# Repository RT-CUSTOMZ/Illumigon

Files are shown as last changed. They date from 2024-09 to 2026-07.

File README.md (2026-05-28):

# 💡 Illumigon

Die modularen smarten Leuchtpanels mit Wifi-Konnektivität, die Ihr auf der Campuswoche bauen könnt.

---

## 📦 Features

- [x] Individuell adressierbare LEDs (WS2811)
- [x] WLAN-fähige Steuerung via ESP32
- [x] Konfigurierbare Animationen und Farbpaletten
- [x] Open Source Hardware + Software (WLED)
- [x] Home Assistant Integration
- [x] Modular steckbar
- [x] Keine Kabelsalat

---

## 📁 Dateiübersicht

| Pfad / Datei | Beschreibung |
|---|---|
| `Fusion 360/` | Fusion 360 Archiv und STEP-Modell |
| `Gerber/` | Leiterplattenlayouts im Gerber Format |
| `KiCad/` | Leiterplattenlayouts im KiCad 9 Format  |
| `STLs/` | 3D-Modell im STL-Format für den 3D-Druck|
| `SVGs/` | Vectorgrafiken zum Laserschneiden und Gravieren |

## 🧾 Stückliste / Teilebestellung

### 🧠 ESP32 WLED Controller

| Bauteil | Referenz | Wert | Footprint | Menge | Link  |
|---|---|---|---|---|---|
| Keramikkondensator | C3, C4, C5, C7, C8, C9, C10 | 100n | SMD 1206 | 7 | |
| Keramikkondensator | C11, C12 | 22u | SMD 1206 | 2 | |
| Elektrolytkondensator | C1 | 470u | C_Elec_10x10.2 | 1 | |
| Keramikkondensator | C2 | 1u0 | SMD 1206 | 1 | |
| Keramikkondensator | C6 | 10u | SMD 1206 | 1 | |
| Dichschichtwiderstand | R3, R6, R9 | 100R | SMD 0805 | 3 | |
| Dichschichtwiderstand | R8, R11, R12 | 10K | SMD 1206 | 3 | |
| Dichschichtwiderstand | R4, R5 | 5K1 | SMD 1206 | 2 | |
| Dichschichtwiderstand | R7, R10 | 4K7 | SMD 0805 | 2 | |
| Dichschichtwiderstand | R1 | 2K0 | SMD 0805 | 1 | |
| Dichschichtwiderstand | R2 | 470R | SMD 0805 | 1 | |
| Leistungsinduktor | L1 | 4u7 | 7.3x6.6mm | 1 | |
| Leuchtdiode | D1, D2, D3, D5, D6 | LED | SMD 0805 | 5 | |
| Schottky-Diode | D4, D7 | SS34 | SMA | 2 | |
| 3.3V Spannungswandler | U1 | AMS1117-3.3 | SOT-223-3 | 1 | |
| 32-bit Mikrocontroller  | U2 | ESP32-WROOM-32E | | 1 | |
| 5V Synchr.-Schaltregler | U3 | AP63205WU | TSOT-23-6 | 1 | |
| 420Mbps Levelshifter | U4 | SN74LVC1T45DBV | SOT-23-6 | 1 | |
| USB-UART Transceiver | U5 | CH340C | SOIC-16 | 1 | |
| Bipolartransistor | Q2, Q3 | BC857 | SOT-23 | 2 | |
| Bipolartransistor | Q4, Q5 | MMBT3904 | SOT-23 | 2 | |
| P-Kanal MOSFET | Q1 | Q_PMOS_GDS | TO-252-2 | 1 | |
| USB-C-Buchse 16-Pin | J1 | USB_C_Receptacle_USB2.0_16P | GCT USB4105 | 1 | |
| Hohlsteckerbuchse | J2 | Barrel_Jack_Switch | | 1 | |
| Pinheader 2.54 2x3 | J3 | Conn_02x03_Odd_Even | 2x03 P2.54mm Vertical | 1 | |

### 💡 Komponenten je Panel

| Bauteil | Referenz | Wert | Footprint | Menge | Link |
|---|---|---|---|---|---|
| Platine | Ecke | | | 3 | [GitHub](https://github.com/RT-CUSTOMZ/Illumigon/blob/V4/Gerber/Ecke.zip) |
| Platine | Seite | | | 3 | [GitHub](https://github.com/RT-CUSTOMZ/Illumigon/blob/V4/Gerber/Seite.zip) |
| Plexiglas | Lichtleiter | 4mm klar | Acrylglas GS | 1 | [GitHub](https://github.com/RT-CUSTOMZ/Illumigon/blob/e6f71768b751d2ca16ff6e7ad1a84dd5374f7dc3/SVGs/Light_Guide_Panel_fein.svg) |
| Plexiglas | Diffusor | 3mm opal | Acrylglas XT opal 70105  | 1 | [GitHub](https://github.com/RT-CUSTOMZ/Illumigon/blob/e6f71768b751d2ca16ff6e7ad1a84dd5374f7dc3/SVGs/Diffusor.svg) |
| Pinheader 2x3  | J1 | 02x03 | Vertikal | 3 | [LCSC](https://www.lcsc.com/product-detail/C492420.html) |
| Pinheader 1x5  | J2, J3 | 01x05 | Horizontal | 6 | [LCSC](https://www.lcsc.com/product-detail/C492413.html) |
| Platine | Verbinder | | | 1 | [GitHub](https://github.com/RT-CUSTOMZ/Illumigon/blob/V4/Gerber/Verbinder.zip) |
| Pinsocket 2x3  | J1, J2 | 02x03 | Vertikal | 2 | [LCSC](https://www.lcsc.com/product-detail/C5116527.html) |
| Pinheader 1x2  | J3, J4 | 01x02 | Vertikal | 2 | [LCSC](https://www.lcsc.com/product-detail/C492401.html) |
| Jumper 1x2 | | 01x02 | | 1 | [LCSC](https://www.lcsc.com/product-detail/C100114.html) |
| Schraube | | PZ 3x10 | | 3 | [Schraubenhimmel](https://www.schraubenhimmel.de/schrauben/senkkopf/spanplattenschrauben-kreuzschlitz/65940/spax-wirox-senkkopf-kreuzschlitz-pz-1-3x10-mm-vollgewinde) |
| 3D-Druck | | Deckel u.  | | 3 | [GitHub](https://github.com/RT-CUSTOMZ/Illumigon/blob/V4/STLs/Deckel_unten%20v49.stl) |
| 3D-Druck | | Deckel m.  | | 3 | [GitHub](https://github.com/RT-CUSTOMZ/Illumigon/blob/V4/STLs/Deckel_mitte%20v45.stl) |
| 3D-Druck | | Verbinder  | | 2 | [GitHub](https://github.com/RT-CUSTOMZ/Illumigon/blob/V4/STLs/Verbinder%20v9.stl) |

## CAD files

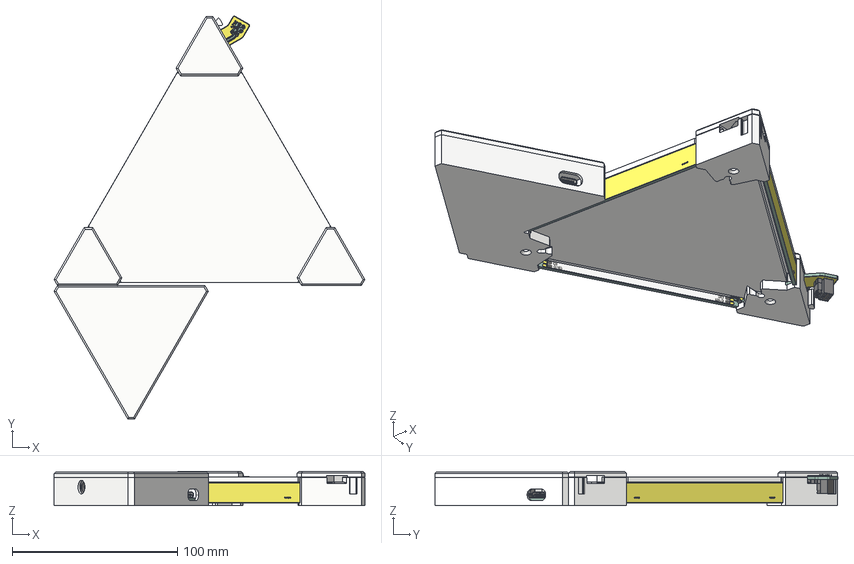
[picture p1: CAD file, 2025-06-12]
Fusion 360/Zusammenbau v36.step
187.9 x 243.6 x 20.8 mm
PinHeader_1x05_P254mm_Horizontal x 6
PinHeader_2x03_P254mm_Vertical x 3
Ecke_track_1 x 3
Ecke_track_2 x 3
Ecke_track_3 x 3
Ecke_track_4 x 3
Ecke_track_5 x 3
Ecke_track_6 x 3
Ecke_track_7 x 3
Ecke_track_8 x 3
Ecke_track_10 x 3
Ecke_track_11 x 3
Ecke_track_12 x 3
Ecke_track_13 x 3
Ecke_track_14 x 3
Ecke_track_15 x 3
Ecke_track_16 x 3
Ecke_track_17 x 3
Ecke_track_18 x 3
Ecke_track_19 x 3
Ecke_track_20 x 3
Ecke_track_21 x 3
Ecke_track_22 x 3
Ecke_track_23 x 3
Ecke_track_24 x 3
Ecke_track_25 x 3
Ecke_zone_1 x 3
Ecke_zone_2 x 3
Ecke_zone_3 x 3
Ecke_zone_4 x 3
Ecke_zone_5 x 3
Ecke_zone_6 x 3
Ecke_zone_7 x 3
Ecke_zone_8 x 3
Ecke_zone_9 x 3
Ecke_zone_10 x 3
Ecke_zone_11 x 3
Ecke_zone_12 x 3
Ecke_zone_13 x 3
Ecke_zone_14 x 3
Ecke_zone_15 x 3
Ecke_zone_16 x 3
Ecke_zone_17 x 3
Ecke_pad_1 x 3
Ecke_pad_2 x 3
Ecke_pad_3 x 3
Ecke_pad_4 x 3
Ecke_pad_5 x 3
Ecke_pad_6 x 3
Ecke_pad_7 x 3
Ecke_pad_8 x 3
Ecke_pad_9 x 3
Ecke_pad_10 x 3
Ecke_pad_11 x 3
Ecke_pad_12 x 3
Ecke_pad_13 x 3
Ecke_pad_14 x 3
Ecke_pad_15 x 3
Ecke_pad_18 x 3
Ecke_pad_19 x 3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

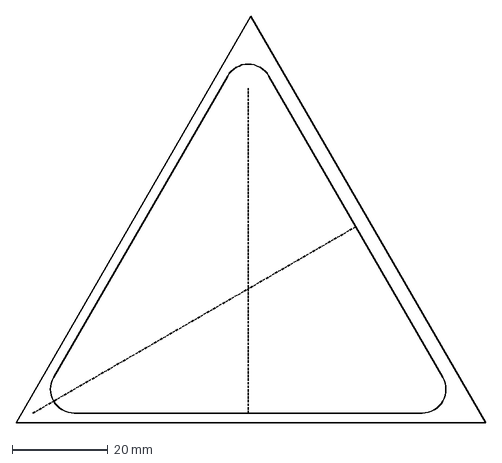
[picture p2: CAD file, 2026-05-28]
KiCad/Controller_v4.3/Dreieck_90mm.dxf
98.1 x 84.9 mm

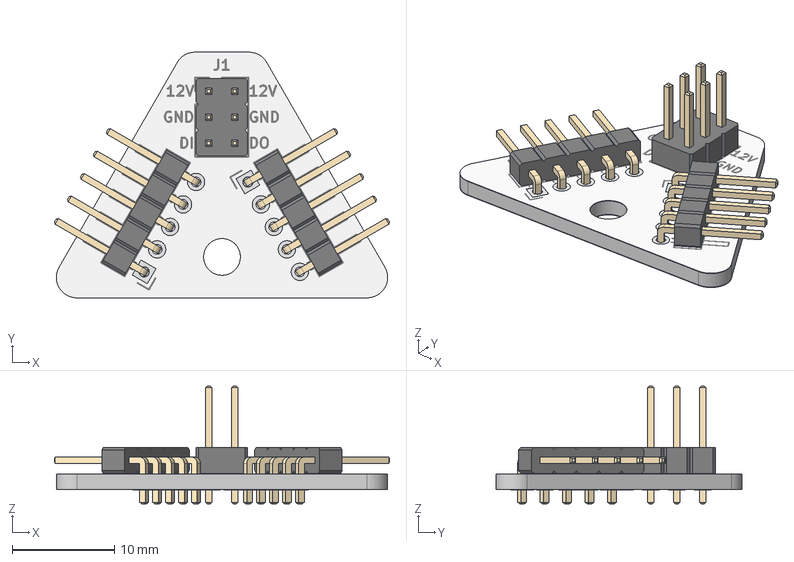
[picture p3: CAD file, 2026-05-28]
KiCad/Ecke/Ecke.step
32.8 x 24.0 x 11.5 mm
PinHeader_1x05_P2.54mm_Horizontal x 2
PinHeader_2x03_P2.54mm_Vertical
Ecke_pad
Ecke_silkscreen
Ecke_soldermask
Ecke_PCB

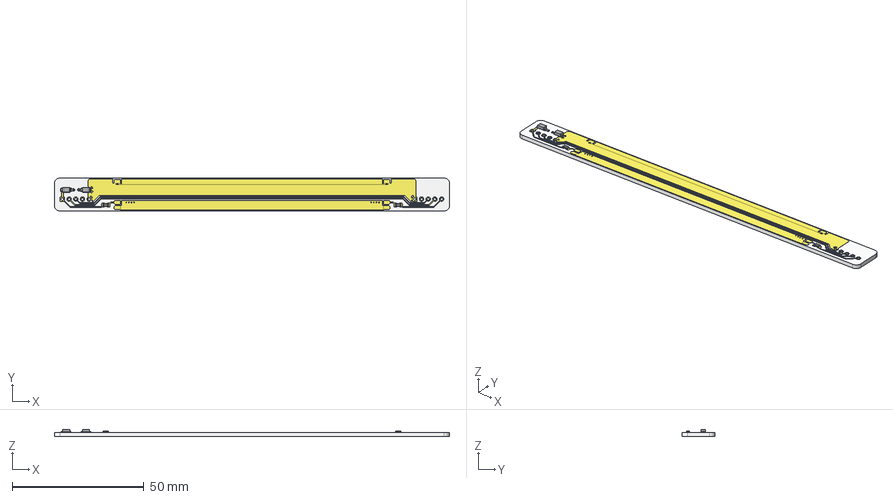
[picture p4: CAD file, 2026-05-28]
KiCad/Seite_v4.3/Seite_v4.3.step
150.0 x 12.5 x 2.63 mm
D_SMF x 2
R_0805_2012Metric x 2
Seite_v4.3_copper
Seite_v4.3_PCB

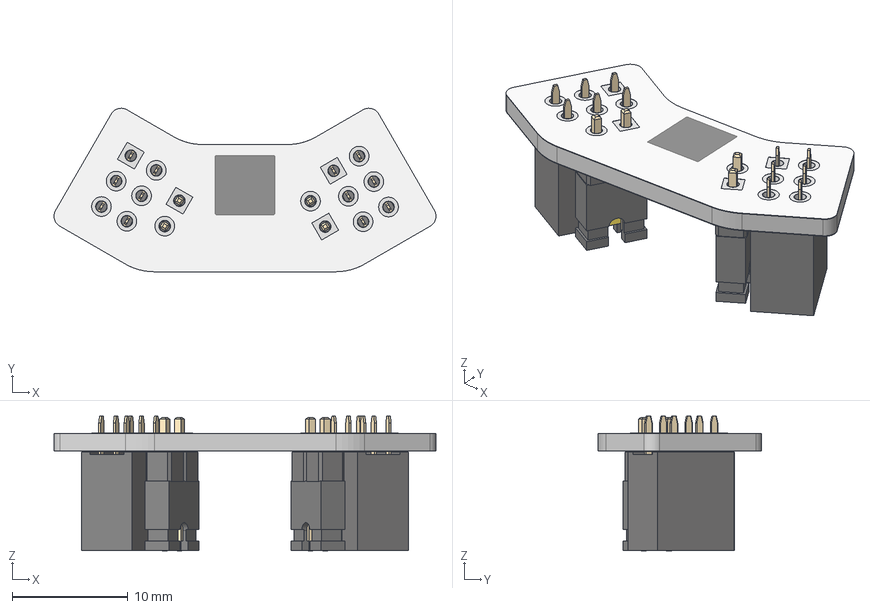
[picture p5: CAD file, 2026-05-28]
KiCad/Verbinder/Verbinder_Jumper.step
33.0 x 14.1 x 11.6 mm
PinSocket_2x03_P2.54mm_Vertical x 2
PinHeader_1x02_P2.54mm_Vertical x 2
Jumper x 2
Verbinder_pad
Verbinder_silkscreen
Verbinder_soldermask
Verbinder_PCB

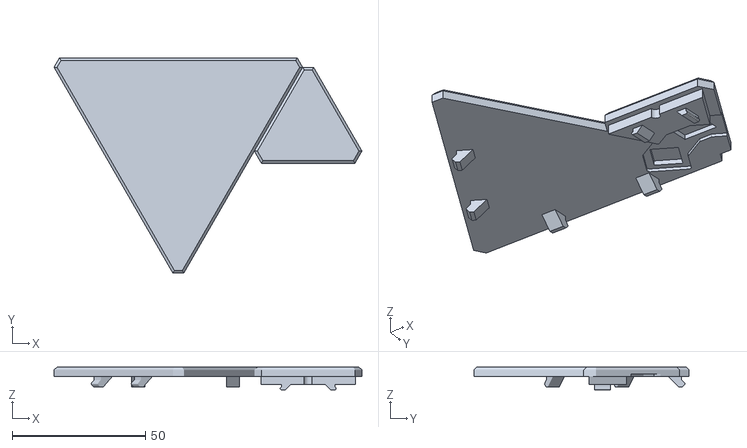
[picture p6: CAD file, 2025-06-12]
STLs/SMD_Controller_Gehäuse_Oberseite_v10.stl
115.4 x 80.7 x 8.50

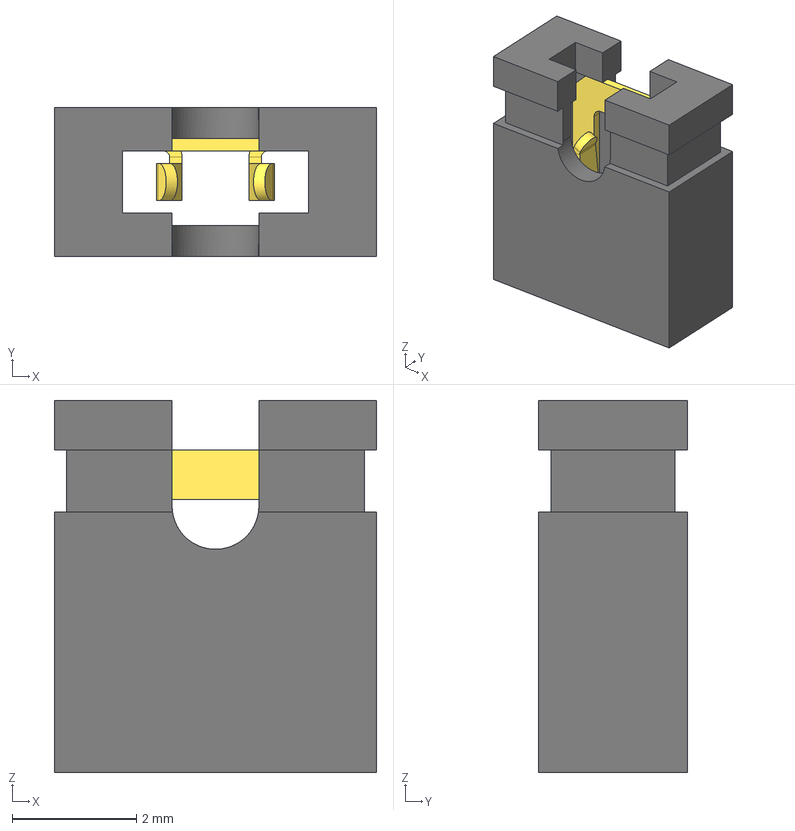
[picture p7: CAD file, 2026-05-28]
KiCad/Verbinder/Jumper.step
5.20 x 2.40 x 6.00 mm

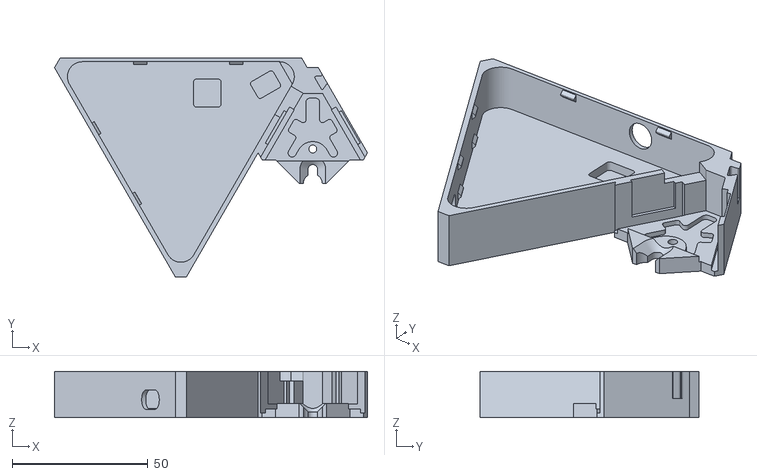
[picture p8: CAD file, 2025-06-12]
STLs/SMD_Controller_Gehäuse_Unterseite_v10.stl
115.4 x 80.7 x 17.0

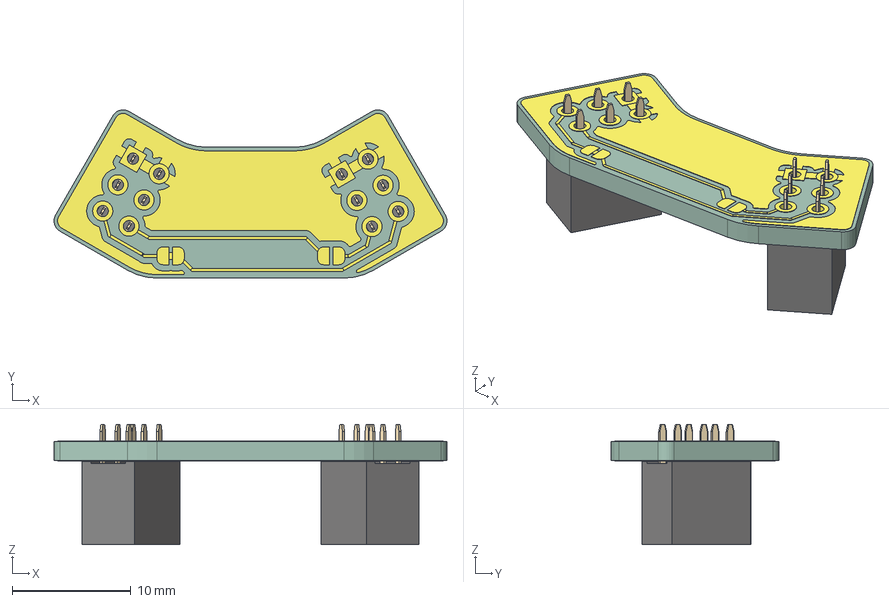
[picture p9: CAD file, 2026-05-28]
KiCad/Verbinder/Verbinder.step
33.0 x 14.1 x 10.1 mm
PinSocket_2x03_P254mm_Vertical x 2
_autosave-Verbinder_track_1
_autosave-Verbinder_track_2
_autosave-Verbinder_track_3
_autosave-Verbinder_track_4
_autosave-Verbinder_track_5
_autosave-Verbinder_track_6
_autosave-Verbinder_track_7
_autosave-Verbinder_track_8
_autosave-Verbinder_track_9
_autosave-Verbinder_track_10
_autosave-Verbinder_track_11
_autosave-Verbinder_track_12
_autosave-Verbinder_track_13
_autosave-Verbinder_track_14
_autosave-Verbinder_track_15
_autosave-Verbinder_track_16
_autosave-Verbinder_zone_1
_autosave-Verbinder_zone_2
_autosave-Verbinder_zone_3
_autosave-Verbinder_zone_4
_autosave-Verbinder_pad_1
_autosave-Verbinder_pad_2
_autosave-Verbinder_pad_3
_autosave-Verbinder_pad_4
_autosave-Verbinder_pad_5
_autosave-Verbinder_pad_6
_autosave-Verbinder_pad_7
_autosave-Verbinder_pad_8
_autosave-Verbinder_pad_9
_autosave-Verbinder_pad_10
_autosave-Verbinder_pad_11
_autosave-Verbinder_pad_12
_autosave-Verbinder_pad_13
_autosave-Verbinder_pad_14
_autosave-Verbinder_pad_15
_autosave-Verbinder_pad_16
_autosave-Verbinder_pad_17
_autosave-Verbinder_pad_18
_autosave-Verbinder_pad_19
_autosave-Verbinder_pad_20
_autosave-Verbinder_pad_21
_autosave-Verbinder_pad_22
_autosave-Verbinder_pad_23
_autosave-Verbinder_pad_24
_autosave-Verbinder_pad_25
_autosave-Verbinder_pad_26
_autosave-Verbinder_pad_27
_autosave-Verbinder_pad_28
_autosave-Verbinder_pad_29
_autosave-Verbinder_pad_30
_autosave-Verbinder_pad_31
_autosave-Verbinder_pad_32
_autosave-Verbinder_pad_33
_autosave-Verbinder_pad_34
_autosave-Verbinder_pad_35
_autosave-Verbinder_pad_36
_autosave-Verbinder_pad_37
_autosave-Verbinder_pad_38
_autosave-Verbinder_pad_39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

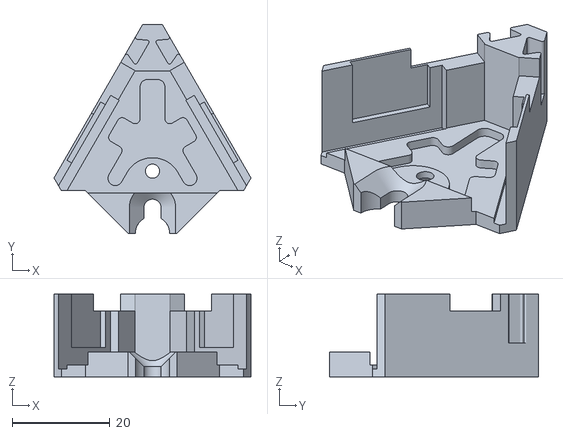
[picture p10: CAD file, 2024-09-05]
STLs/Deckel_unten v49.stl
40.4 x 42.8 x 17.0

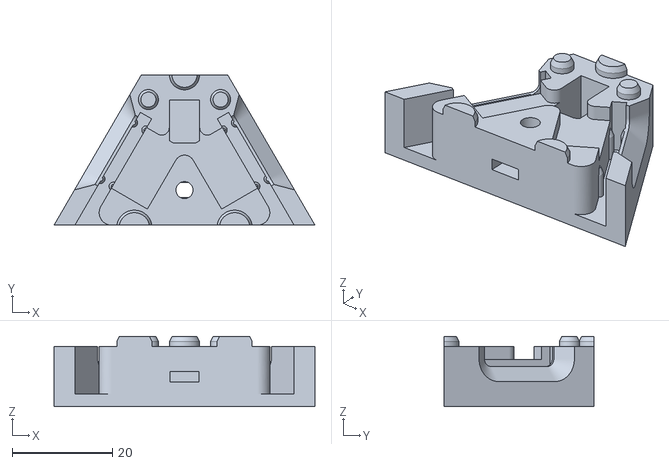
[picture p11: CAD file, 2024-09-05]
STLs/Löthilfe v13.stl
52.1 x 30.0 x 14.0

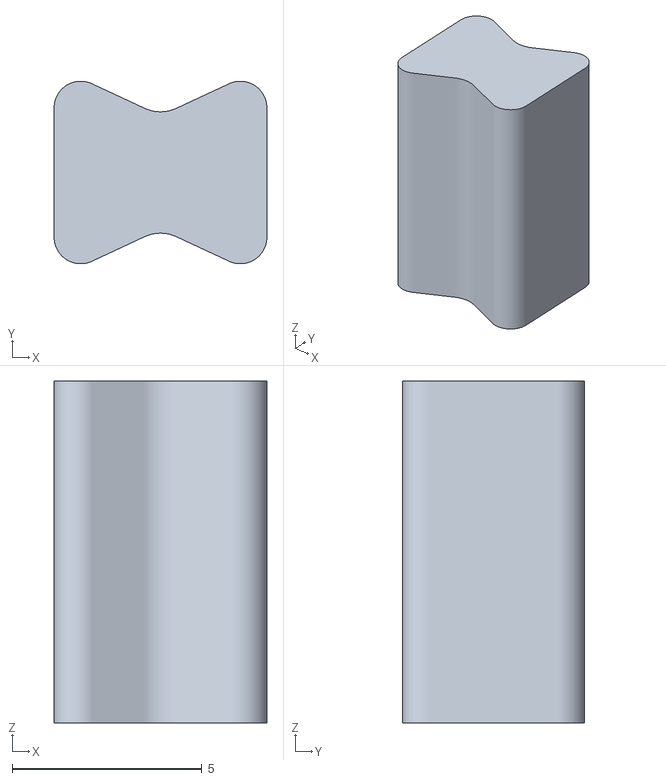
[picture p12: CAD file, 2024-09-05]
STLs/Verbinder v9.stl
5.60 x 4.80 x 9.00

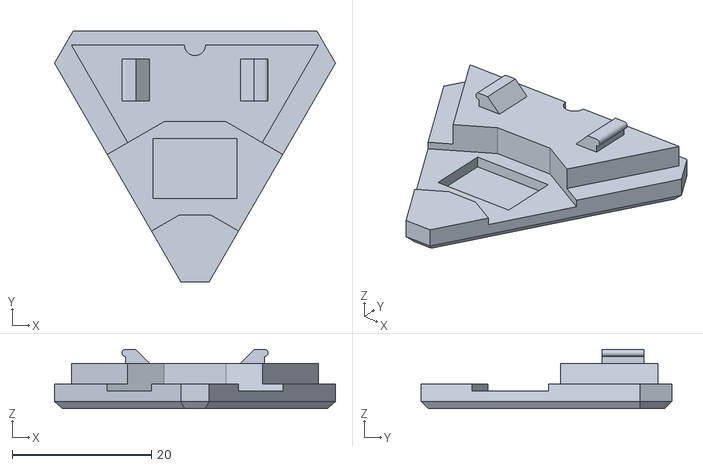
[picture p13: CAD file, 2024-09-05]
STLs/Deckel_oben v48.stl
40.4 x 36.0 x 8.50

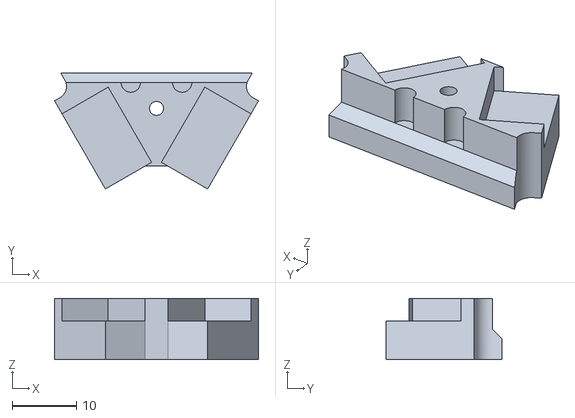
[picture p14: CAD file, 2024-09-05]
STLs/Deckel_mitte v45.stl
31.7 x 18.0 x 9.50

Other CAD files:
Fusion 360/Löthilfe v13.f3z
Fusion 360/Zusammenbau v36.f3z

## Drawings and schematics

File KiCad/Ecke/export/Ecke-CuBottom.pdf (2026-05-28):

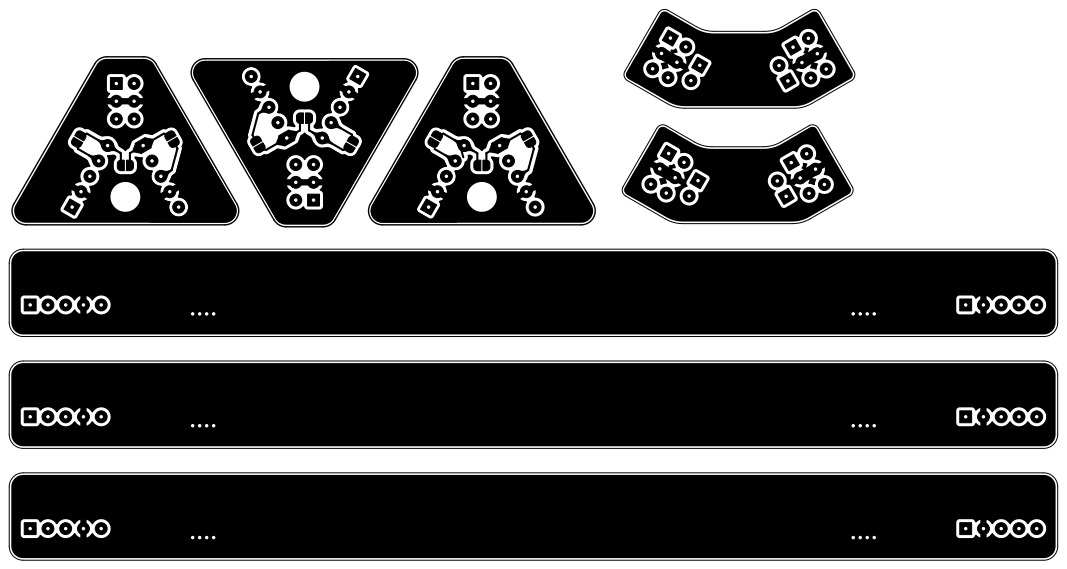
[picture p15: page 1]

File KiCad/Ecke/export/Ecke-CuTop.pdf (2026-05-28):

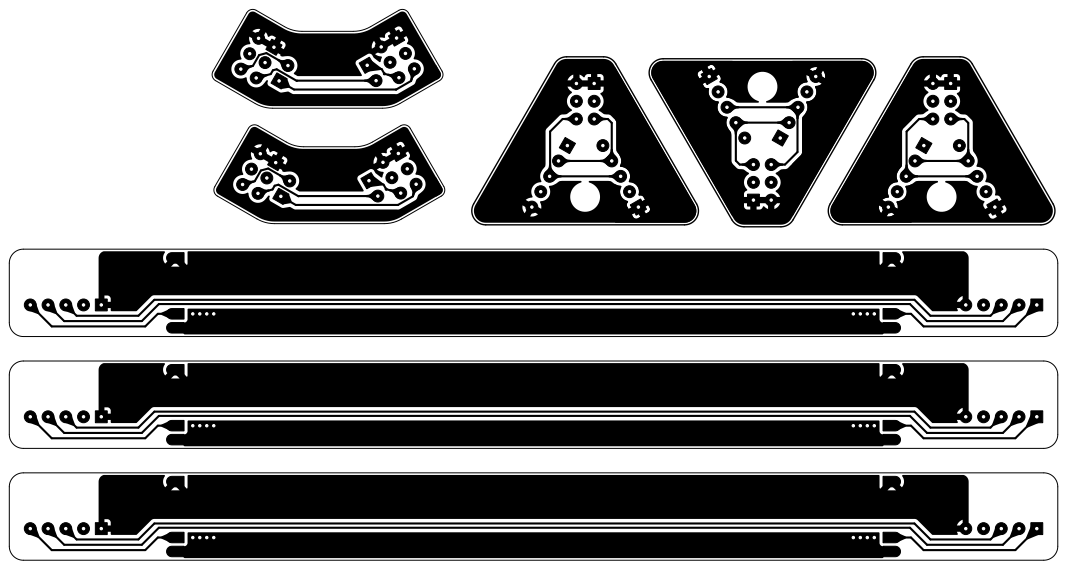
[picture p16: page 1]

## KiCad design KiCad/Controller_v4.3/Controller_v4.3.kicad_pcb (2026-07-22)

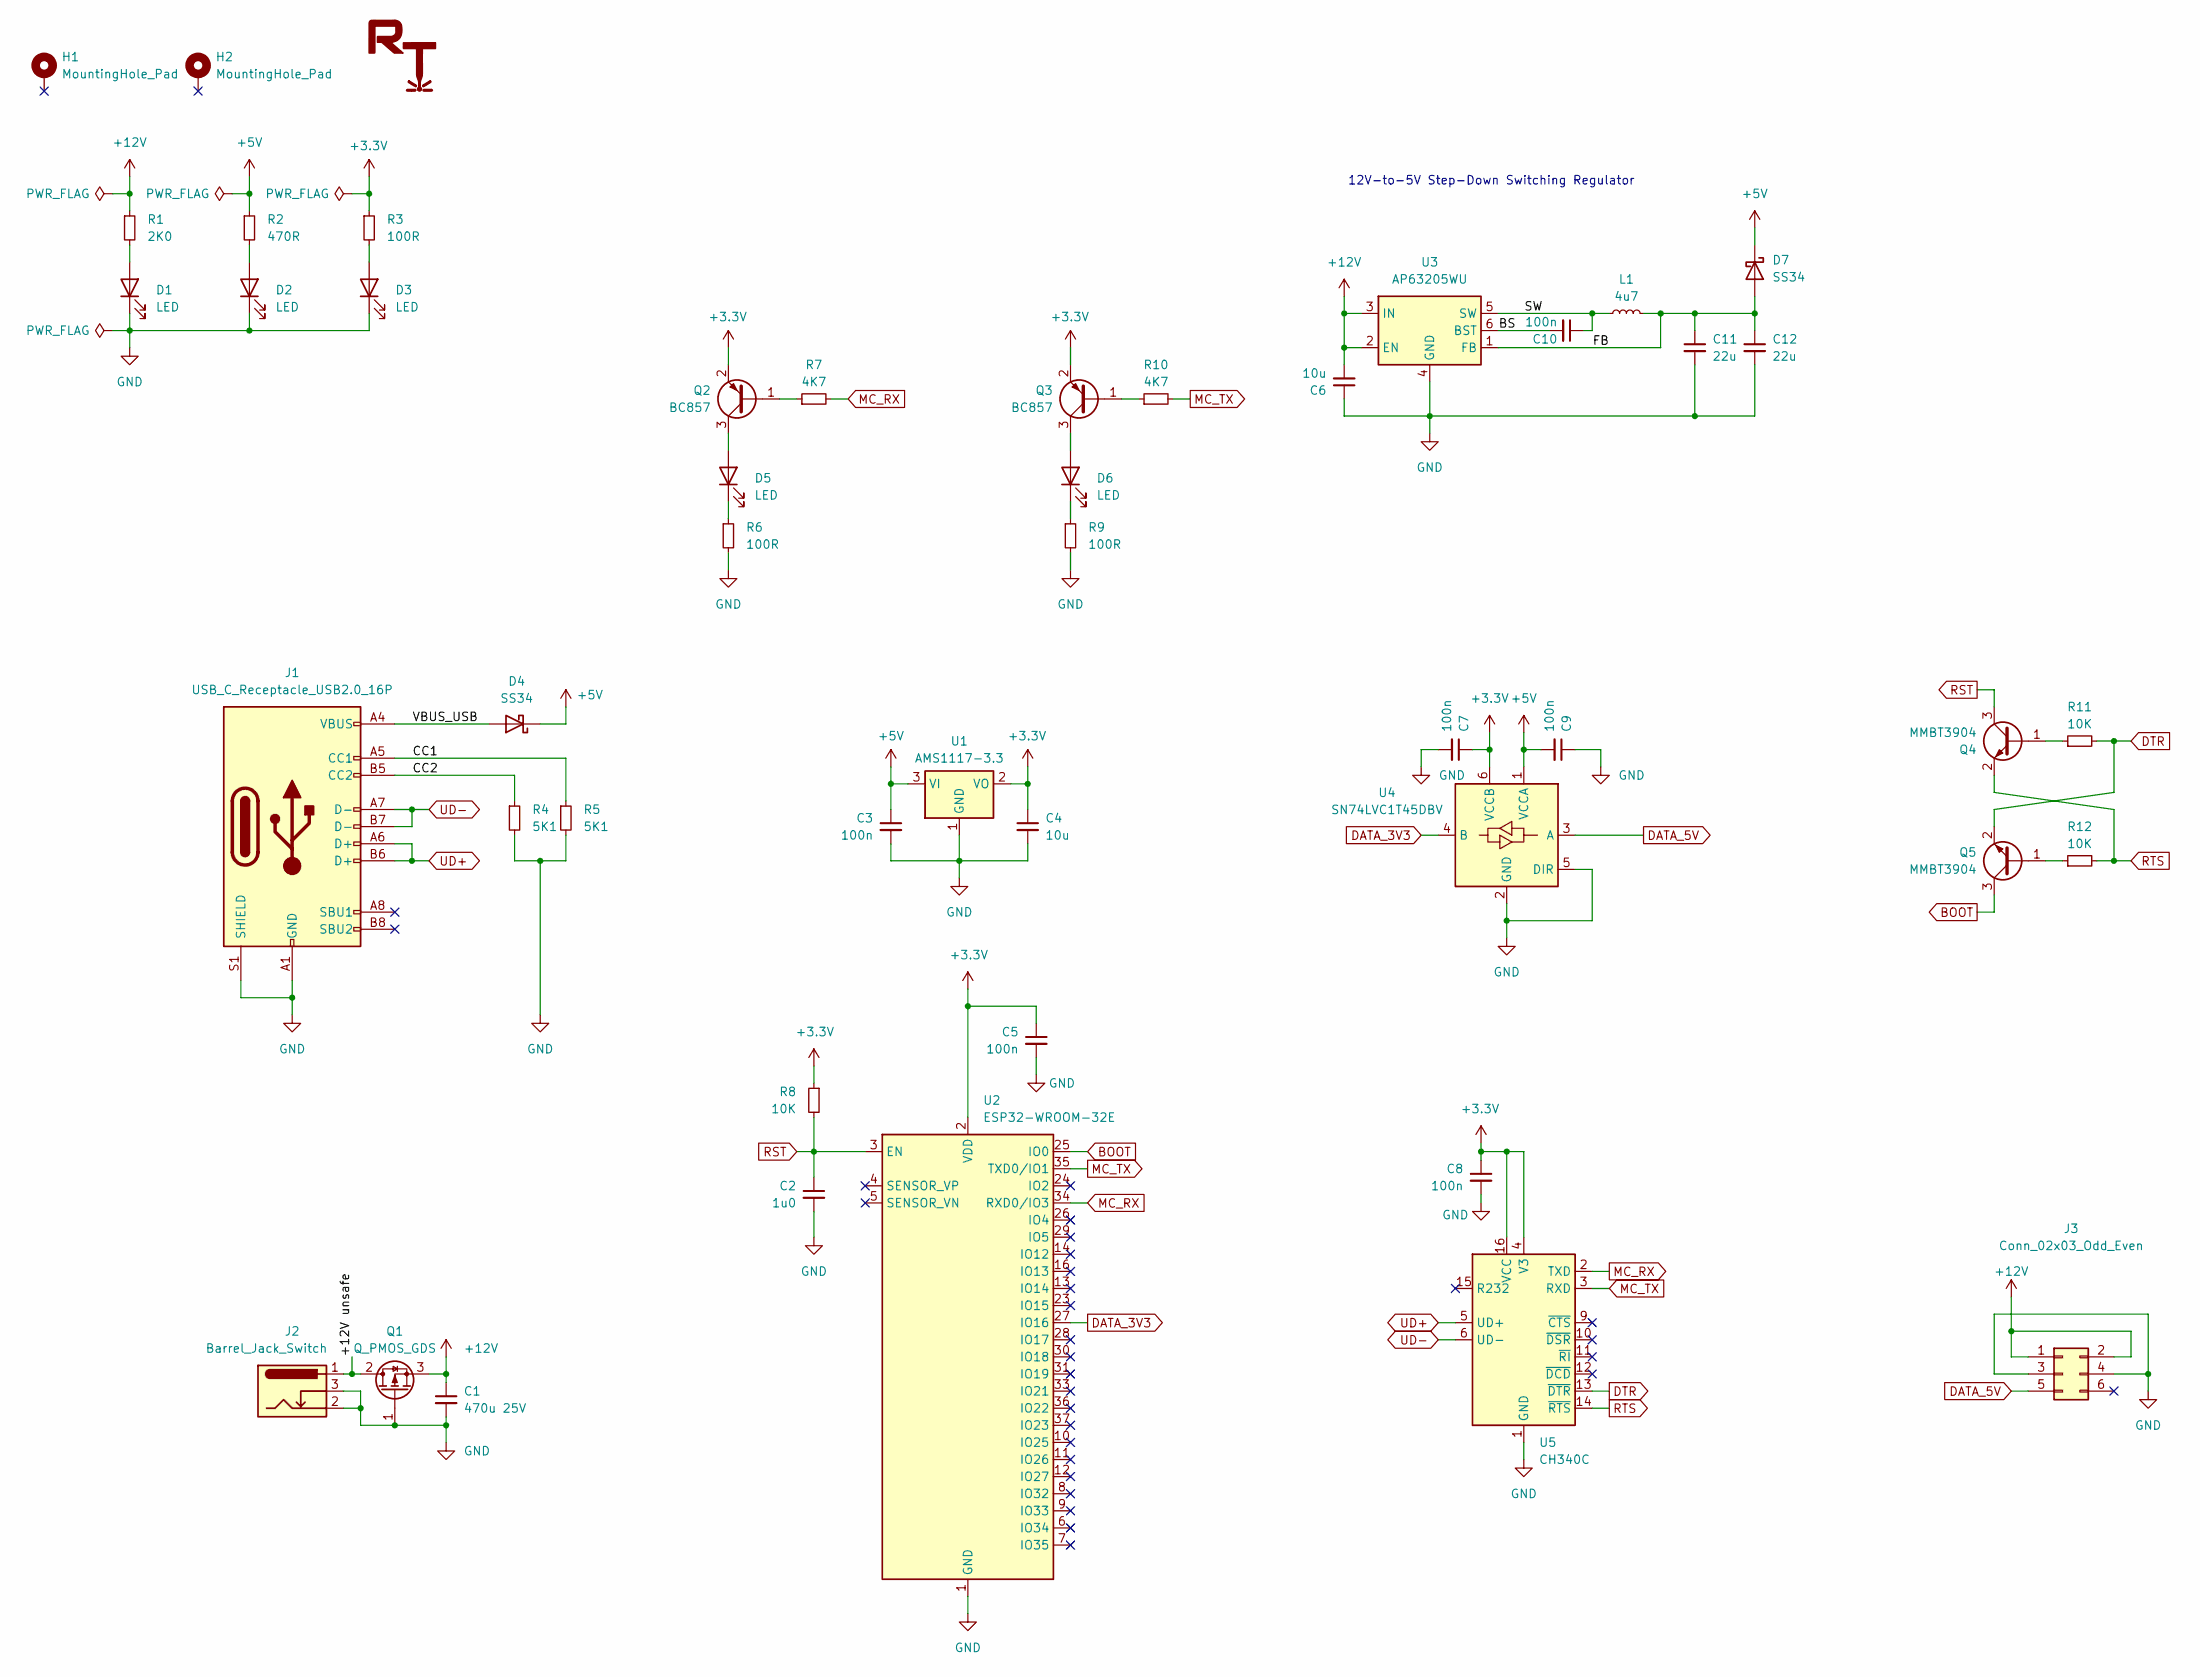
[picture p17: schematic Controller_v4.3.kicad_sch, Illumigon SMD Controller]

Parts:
C1: 470u 25V; C_Elec_10x10.2; Part Number EEE-FK1E471AP
C2: 1u0; C_1206_3216Metric_Pad1.33x1.80mm_HandSolder
C3, C5, C7, C8, C9, C10: 100n; C_1206_3216Metric_Pad1.33x1.80mm_HandSolder
C4, C6: 10u; C_1206_3216Metric_Pad1.33x1.80mm_HandSolder; Part Number CL31B106KAHNNNE
C11, C12: 22u; C_1206_3216Metric_Pad1.33x1.80mm_HandSolder; Part Number CL31B226MPHNNNE
D1, D2, D3, D5, D6: LED; LED_0805_2012Metric_Pad1.15x1.40mm_HandSolder
D4, D7: SS34; D_SMA
H1, H2: MountingHole_Pad; MountingHole_3.2mm_M3_DIN965_Pad_TopBottom
J1: USB_C_Receptacle_USB2.0_16P; USB_C_Receptacle_GCT_USB4105-xx-A_16P_TopMnt_Horizontal; Part Number USB4105-GF-A-120
J2: Barrel_Jack_Switch; BarrelJack_Horizontal
J3: Conn_02x03_Odd_Even; PinHeader_2x03_P2.54mm_Vertical
L1: 4u7; L_Chilisin_BMRB00060624
Q1: Q_PMOS_GDS; TO-252-2
Q2, Q3: BC857; SOT-23
Q4, Q5: MMBT3904; SOT-23
R1: 2K0; R_0805_2012Metric_Pad1.20x1.40mm_HandSolder
R2: 470R; R_0805_2012Metric_Pad1.20x1.40mm_HandSolder
R3, R6, R9: 100R; R_0805_2012Metric_Pad1.20x1.40mm_HandSolder
R4, R5: 5K1; R_1206_3216Metric_Pad1.30x1.75mm_HandSolder
R7, R10: 4K7; R_0805_2012Metric_Pad1.20x1.40mm_HandSolder
R8, R11, R12: 10K; R_1206_3216Metric_Pad1.30x1.75mm_HandSolder
SYM1: RT_Logo_10mm_Silkscreen
U1: AMS1117-3.3; SOT-223-3_TabPin2
U2: ESP32-WROOM-32E; ESP32-WROOM-32D
U3: AP63205WU; TSOT-23-6
U4: SN74LVC1T45DBV; SOT-23-6
U5: CH340C; SOIC-16_3.9x9.9mm_P1.27mm

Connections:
+3.3V: C4.1, C5.1, C7.1, C8.1, Q2.2 (E), Q3.2 (E), R3.1, R8.1, U1.2 (VO), U2.2 (VDD), U4.6 (VCCB), U5.4 (V3), U5.16 (VCC)
+5V: C3.1, C9.2, D4.1 (K), D7.1 (K), R2.1, U1.3 (VI), U4.1 (VCCA)
+12V: C1.1, C6.2, J3.1, J3.2, Q1.3 (S), R1.1, U3.2 (EN), U3.3 (IN)
/+12V unsafe: J2.1, Q1.2 (D)
/BS: C10.2, U3.6 (BST)
/CC1: J1.A5 (CC1), R5.1
/CC2: J1.B5 (CC2), R4.1
/FB: C11.1, C12.1, D7.2 (A), L1.2, U3.1 (FB)
/SW: C10.1, L1.1, U3.5 (SW)
/VBUS_USB: D4.2 (A), J1.A4 (VBUS), J1.A9 (VBUS), J1.B4 (VBUS), J1.B9 (VBUS)
BOOT: Q5.3 (C), U2.25 (IO0)
DATA_3V3: U2.27 (IO16), U4.4 (B)
DATA_5V: J3.5, U4.3 (A)
DTR: Q5.2 (E), R11.2, U5.13 (~DTR)
GND: C1.2, C2.2, C3.2, C4.2, C5.2, C6.1, C7.2, C8.2, C9.1, C11.2, C12.2, D1.1 (K), D2.1 (K), D3.1 (K), J1.A1 (GND), J1.A12 (GND), J1.B1 (GND), J1.B12 (GND), J1.S1 (SHIELD), J2.2, J2.3, J3.3, J3.4, Q1.1 (G), R4.2, R5.2, R6.2, R9.2, U1.1 (GND), U2.1 (GND), U2.15 (GND), U2.38 (GND), U2.39 (GND), U3.4 (GND), U4.2 (GND), U4.5 (DIR), U5.1 (GND)
MC_RX: R7.2, U2.34 (RXD0/IO3), U5.2 (TXD)
MC_TX: R10.2, U2.35 (TXD0/IO1), U5.3 (RXD)
unnamed: D1.2 (A), R1.2
unnamed: D2.2 (A), R2.2
unnamed: D3.2 (A), R3.2
unnamed: D5.2 (A), Q2.3 (C)
unnamed: D5.1 (K), R6.1
unnamed: D6.2 (A), Q3.3 (C)
unnamed: D6.1 (K), R9.1
unnamed: Q2.1 (B), R7.1
unnamed: Q3.1 (B), R10.1
unnamed: Q4.1 (B), R11.1
unnamed: Q5.1 (B), R12.1
RST: C2.1, Q4.3 (C), R8.2, U2.3 (EN)
RTS: Q4.2 (E), R12.2, U5.14 (~RTS)
UD+: J1.A6 (D+), J1.B6 (D+), U5.5 (UD+)
UD-: J1.A7 (D-), J1.B7 (D-), U5.6 (UD-)

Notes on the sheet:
12V-to-5V Step-Down Switching Regulator

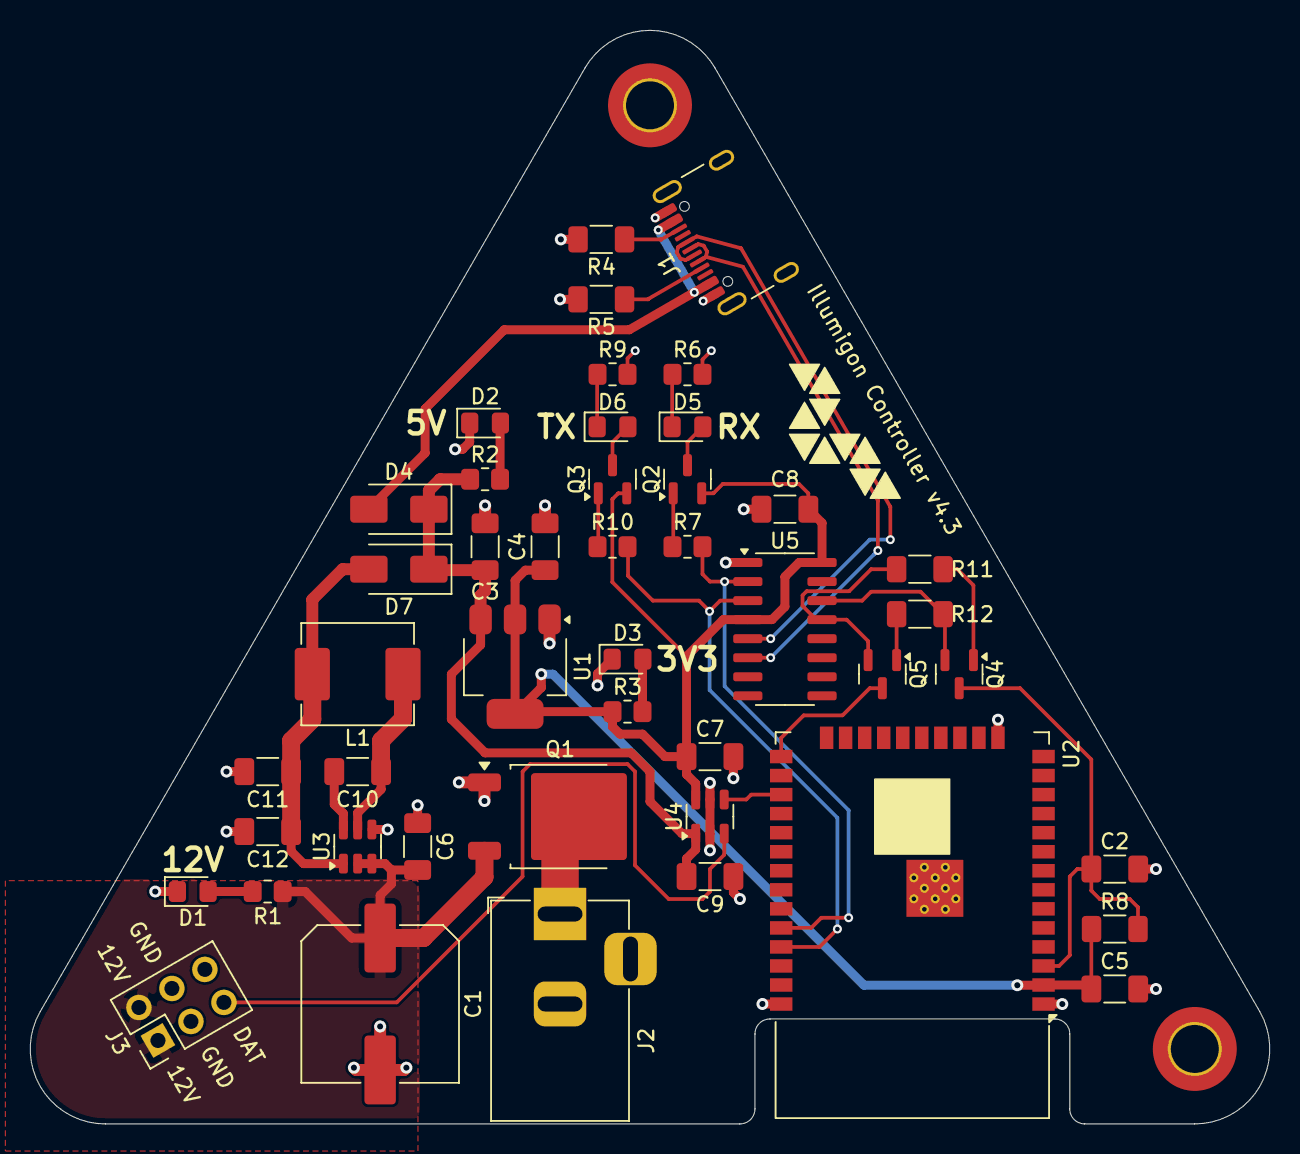
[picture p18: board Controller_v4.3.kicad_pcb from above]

Board: 2 copper layers, 82.7 x 72.9 mm, 48 parts (1 on the bottom side), 32 nets.

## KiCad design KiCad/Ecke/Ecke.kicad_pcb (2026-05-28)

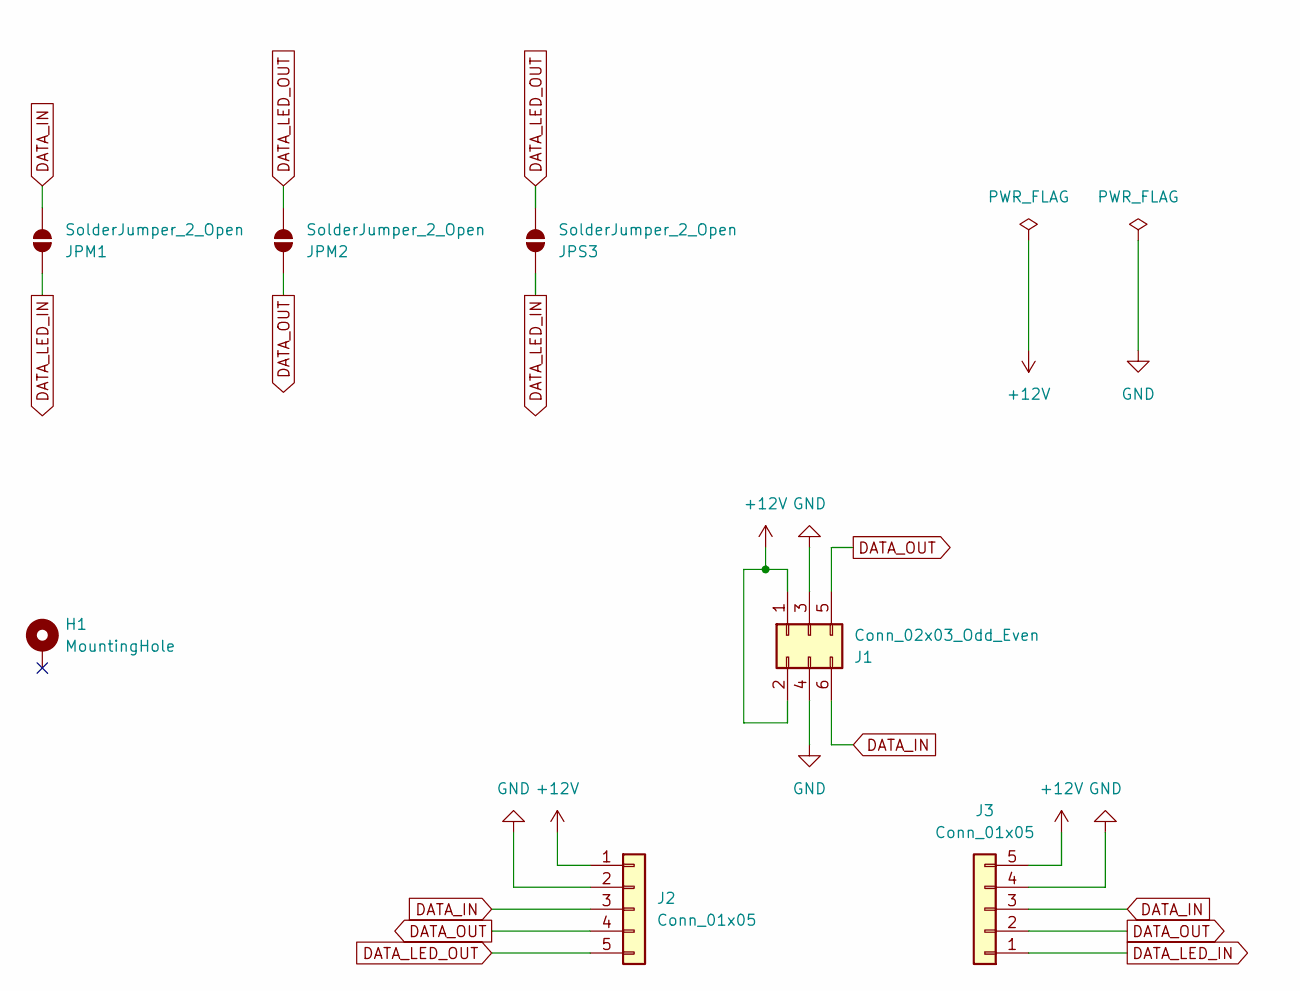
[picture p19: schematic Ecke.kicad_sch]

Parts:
H1: MountingHole; MountingHole_3.2mm_M3
J1: Conn_02x03_Odd_Even; PinHeader_2x03_P2.54mm_Vertical
J2, J3: Conn_01x05; PinHeader_1x05_P2.54mm_Horizontal_short_Silk
JPM1, JPM2: SolderJumper_2_Open; SolderJumper-2_P1.3mm_Open_RoundedPad1.0x1.5mm
JPS3: SolderJumper_2_Open; SolderJumper-2_P1.3mm_Open_RoundedPad1.0x1.5mm

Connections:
+12V: J1.1, J1.2, J2.1, J3.5
DATA_IN: J1.6, J2.3, J3.3, JPM1.1 (A)
DATA_LED_IN: J3.1, JPM1.2 (B), JPS3.2 (B)
DATA_LED_OUT: J2.5, JPM2.1 (A), JPS3.1 (A)
DATA_OUT: J1.5, J2.4, J3.2, JPM2.2 (B)
GND: J1.3, J1.4, J2.2, J3.4

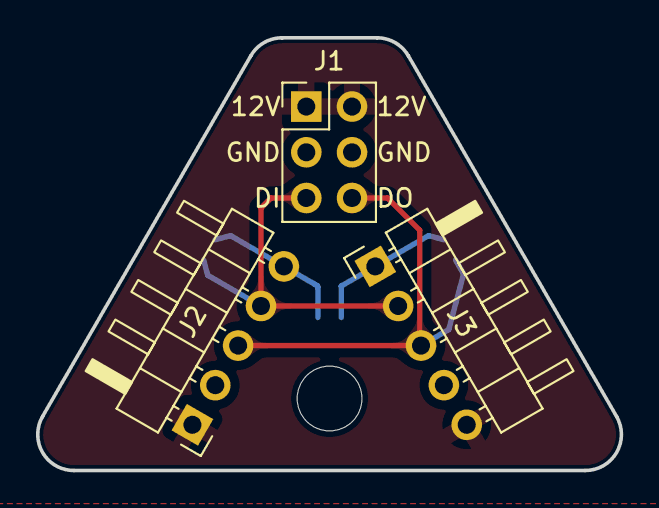
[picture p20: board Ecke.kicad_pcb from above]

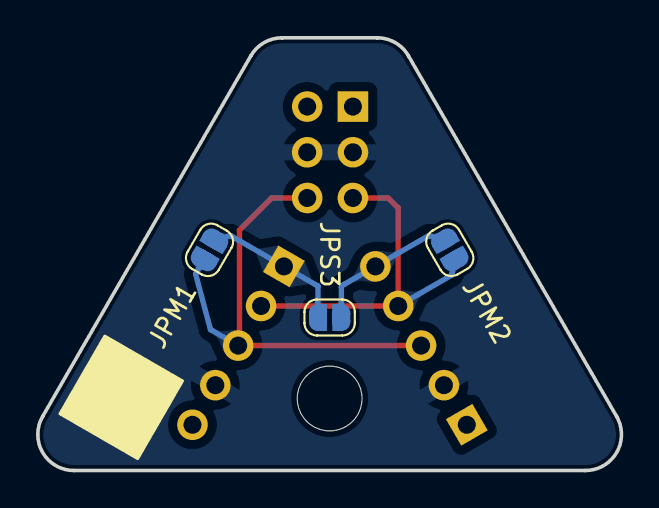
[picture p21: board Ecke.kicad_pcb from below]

Board: 2 copper layers, 32.4 x 24.0 mm, 7 parts (3 on the bottom side), 6 nets.

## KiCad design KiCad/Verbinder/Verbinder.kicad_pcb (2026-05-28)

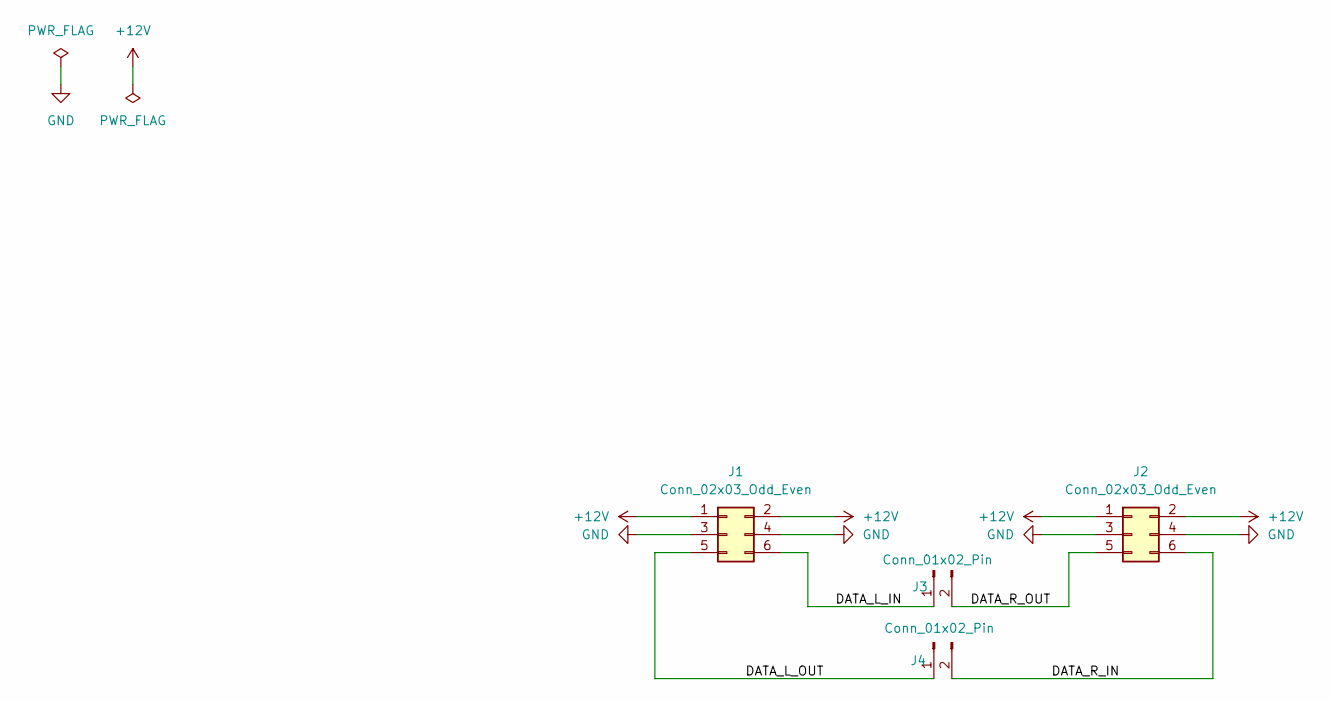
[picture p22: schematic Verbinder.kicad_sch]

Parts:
J1, J2: Conn_02x03_Odd_Even; PinSocket_2x03_P2.54mm_Vertical
J3, J4: Conn_01x02_Pin; PinHeader_1x02_P2.54mm_Vertical

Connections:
+12V: J1.1, J1.2, J2.1, J2.2
/DATA_L_IN: J1.6, J3.1
/DATA_L_OUT: J1.5, J4.1
/DATA_R_IN: J2.6, J4.2
/DATA_R_OUT: J2.5, J3.2
GND: J1.3, J1.4, J2.3, J2.4

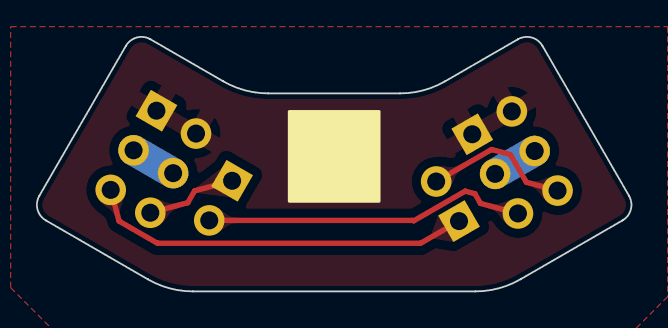
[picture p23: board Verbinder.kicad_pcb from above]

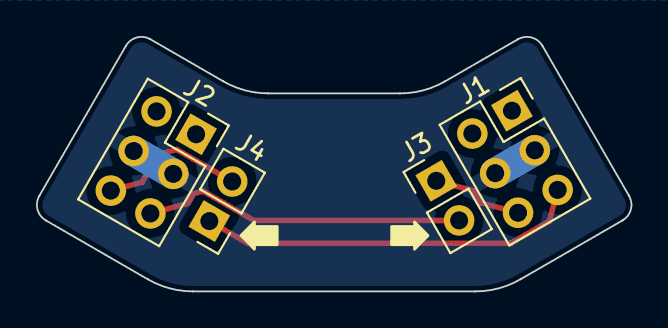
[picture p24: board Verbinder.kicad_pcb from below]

Board: 2 copper layers, 33.0 x 14.1 mm, 4 parts (4 on the bottom side), 6 nets.

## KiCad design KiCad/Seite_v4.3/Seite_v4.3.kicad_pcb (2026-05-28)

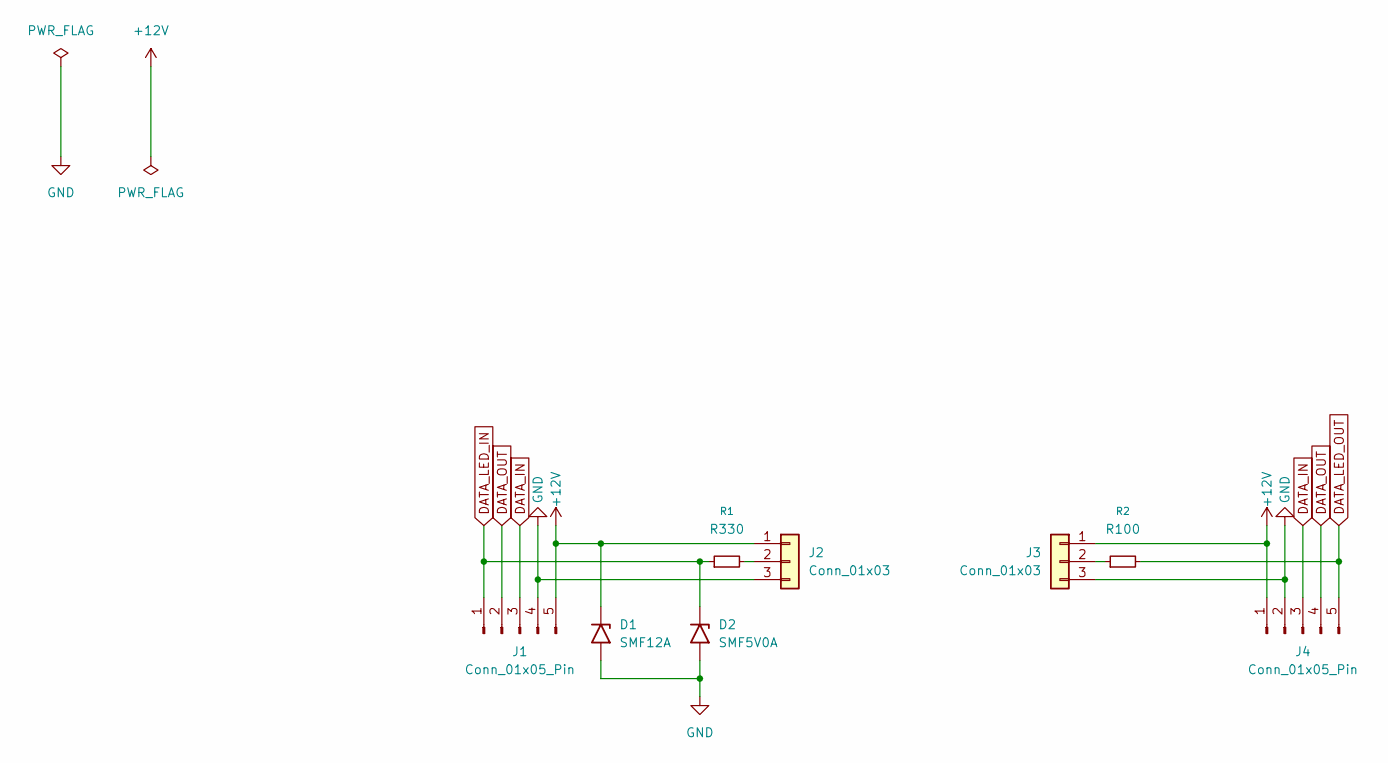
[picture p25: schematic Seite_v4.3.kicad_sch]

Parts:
D1: SMF12A; D_SMF
D2: SMF5V0A; D_SMF
J1, J4: Conn_01x05_Pin; PinSocket_1x05_P2.54mm_Vertical
J2: Conn_01x03; FCOB RGB LED Strip links
J3: Conn_01x03; FCOB RGB LED Strip rechts
R1: R330; R_0805_2012Metric_Pad1.20x1.40mm_HandSolder
R2: R100; R_0805_2012Metric_Pad1.20x1.40mm_HandSolder

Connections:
+12V: D1.1 (A1), J1.5, J2.1, J3.1, J4.1
DATA_IN: J1.3, J4.3
DATA_LED_IN: D2.1 (A1), J1.1, R1.1
DATA_LED_OUT: J4.5, R2.2
DATA_OUT: J1.2, J4.4
GND: D1.2 (A2), D2.2 (A2), J1.4, J2.3, J3.3, J4.2
unnamed: J2.2, R1.2
unnamed: J3.2, R2.1

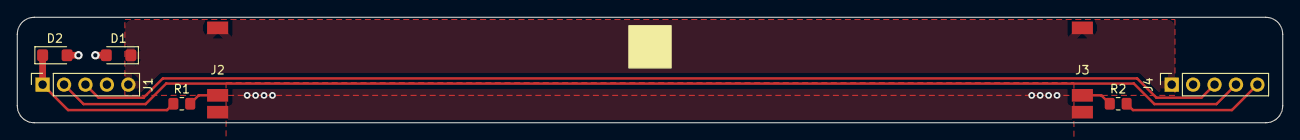
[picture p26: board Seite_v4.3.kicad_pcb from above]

Board: 2 copper layers, 150.0 x 12.5 mm, 8 parts (0 on the bottom side), 8 nets.

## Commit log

2026-05-28 V4.3 Controller und Seite KiCad Dateien
    [Controller_v4.3.kicad_pcb, Controller_v4.3.kicad_sch, Dreieck_90mm.dxf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]
2026-05-28 Ecke und Verbinder hinzugefuegt
    [Ecke-BOT.gbr, Ecke-B_Cu.gbr, Ecke-B_Cu_UV.gbr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]
2026-05-28 Relabeled Components
    [Controller_v4.3.kicad_pcb, Controller_v4.3.kicad_sch]
2026-07-22 Consolidate controller bom
    [Controller_v4.3.kicad_pcb, Controller_v4.3.kicad_sch]
